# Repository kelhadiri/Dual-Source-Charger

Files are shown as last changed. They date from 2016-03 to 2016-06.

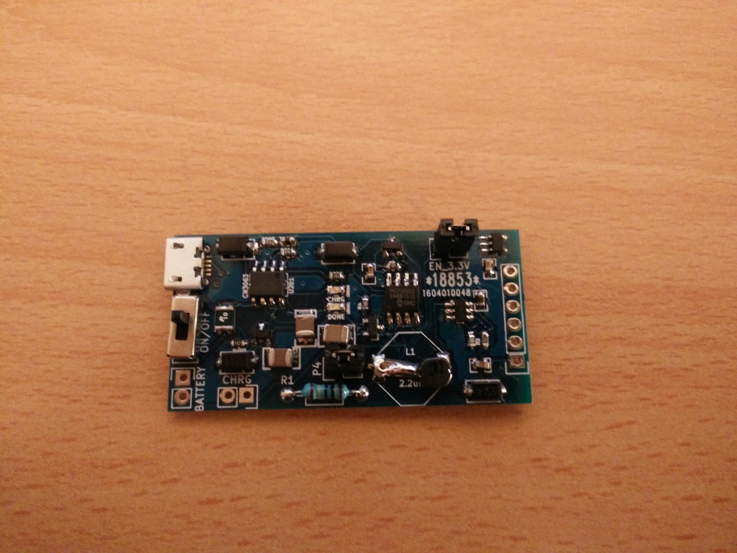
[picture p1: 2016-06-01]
Images/2016-05-27 23.27.27.jpg

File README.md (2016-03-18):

Dual Source Charger
=============
Currently seeking a new, flashier name.

This project is a dual power source charger that breaks out to 3.3v and 5v.

An example use case would be a solar panel or usb connection to charge a lipo driving an ESP8266 or an Arduino.

The dual power circuit is mostly taken from https://github.com/CCHS-Melbourne/ESPlant

CREDITS
------------

This project was designed by [John Spencer](https://github.com/mage0r)
With a special thanks to [Angus Gratton](https://github.com/projectgus)

Made at hackmelbourne.org!

SPECIAL THANKS
------------

To the HackMelbourne (CCHS, http://hackmelbourne.org) community of Melbourne, Australia.

To all other open-source developers whose countless hours supported every other aspect of this design.

DISTRIBUTION
------------
The specific terms of distribution of this project are governed by the
license referenced below. Please contact the copyright owner if you wish to modify the board for distribution. Please utilize this design for personal or research projects. Please acknowledge all contributors.

LICENSE
-------
Licensed under the TAPR Open Hardware License (www.tapr.org/OHL).
The "license" sub-folder also contains a copy of this license in plain text format.

Copyright John Spencer, Angus Gratton 2016

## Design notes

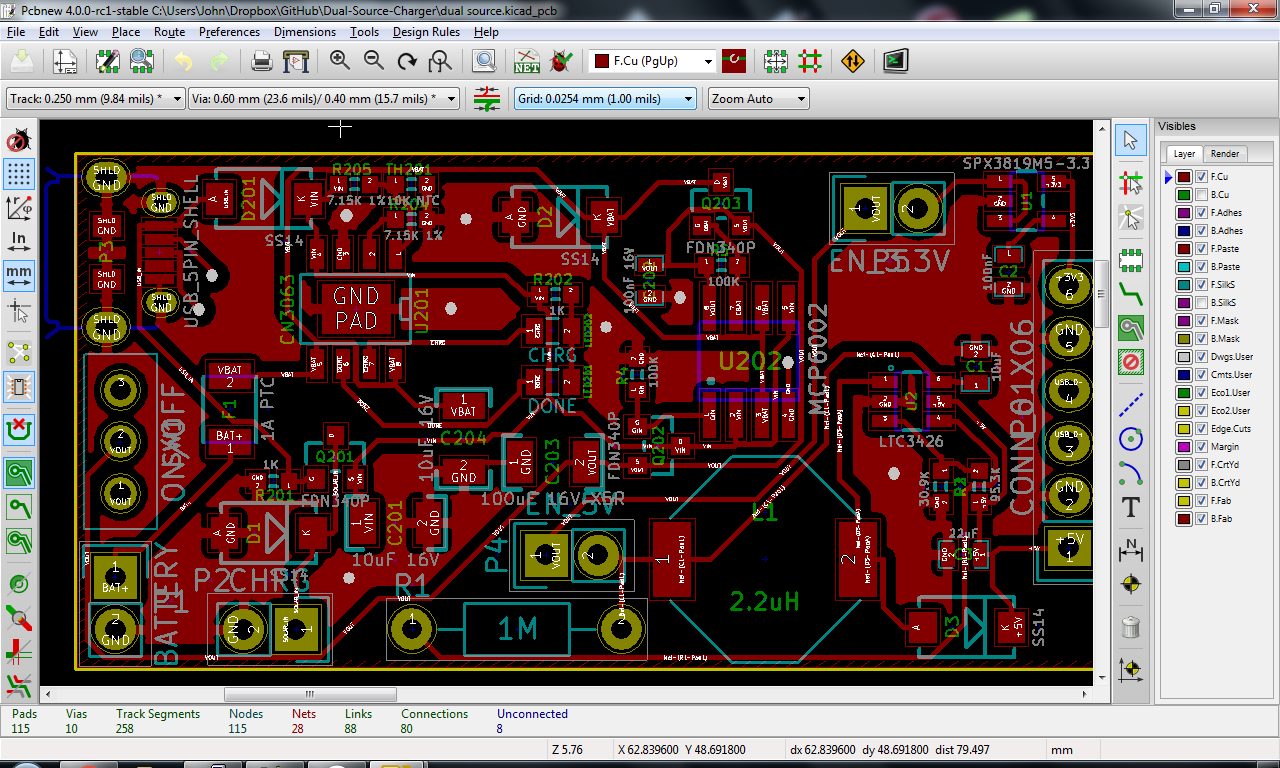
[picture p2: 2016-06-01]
Images/Screenshot 2016-06-01 21.16.20.png

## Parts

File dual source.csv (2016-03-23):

Id | Designator | Package | Quantity | Designation | Supplier and ref
1 | U1 | SOT23-5 | 1 | SPX3819M5-3.3
2 | C1 | 0603_CAP | 1 | 10uF
3 | C2 | 0603_CAP | 1 | 100nF
4 | C3 | 0603_CAP | 1 | 22uF
5 | C201,C204 | 1210_CAP | 2 | 10uF 16V
6 | C202 | 0603_CAP | 1 | 100nF 16V
7 | C203 | 1210_CAP | 1 | 100uF 16V X5R
8 | D1,D2,D3,D201 | DIODE_SMA | 4 | SS14
9 | F1 | 1210 | 1 | 1A PTC
10 | L1 | IND_SRU1038 | 1 | 2.2uH
11 | P1 | Pin_Header_Straight_1x02 | 1 | BATTERY
12 | P2 | Pin_Header_Straight_1x02 | 1 | CHRG
13 | P3 | USB-MICRO-5pin_PTHMOUNT | 1 | USB_5PIN_SHELL
14 | P4 | Pin_Header_Straight_1x02 | 1 | EN_5V
15 | P5 | Pin_Header_Straight_1x02 | 1 | EN_3.3V
16 | P6 | Pin_Header_Straight_1x06 | 1 | CONN_01X06
17 | Q201,Q202,Q203 | SOT23_FET | 3 | FDN340P
18 | R1 | Resistor_Horizontal_RM10mm | 1 | 1M
19 | R2 | 0603 | 1 | 95.3K
20 | R3 | 0603 | 1 | 30.9K
21 | R4,R5 | 0603 | 2 | 100K
22 | R201,R202 | 0603 | 2 | 1K
23 | R204,R205 | 0603 | 2 | 7.15K 1%
24 | SW1 | SS12D00 | 1 | ON/OFF
25 | TH201 | 0603 | 1 | 10K NTC
26 | U201 | CN3063_SOIC8_EP | 1 | CN3063
27 | U202 | SO08_4mm | 1 | MCP6002
28 | LED201 | 0805 | 1 | LED_GREEN
29 | LED202 | 0805 | 1 | LED_RED
30 | U2 | SOT23-6 | 1 | LTC3426

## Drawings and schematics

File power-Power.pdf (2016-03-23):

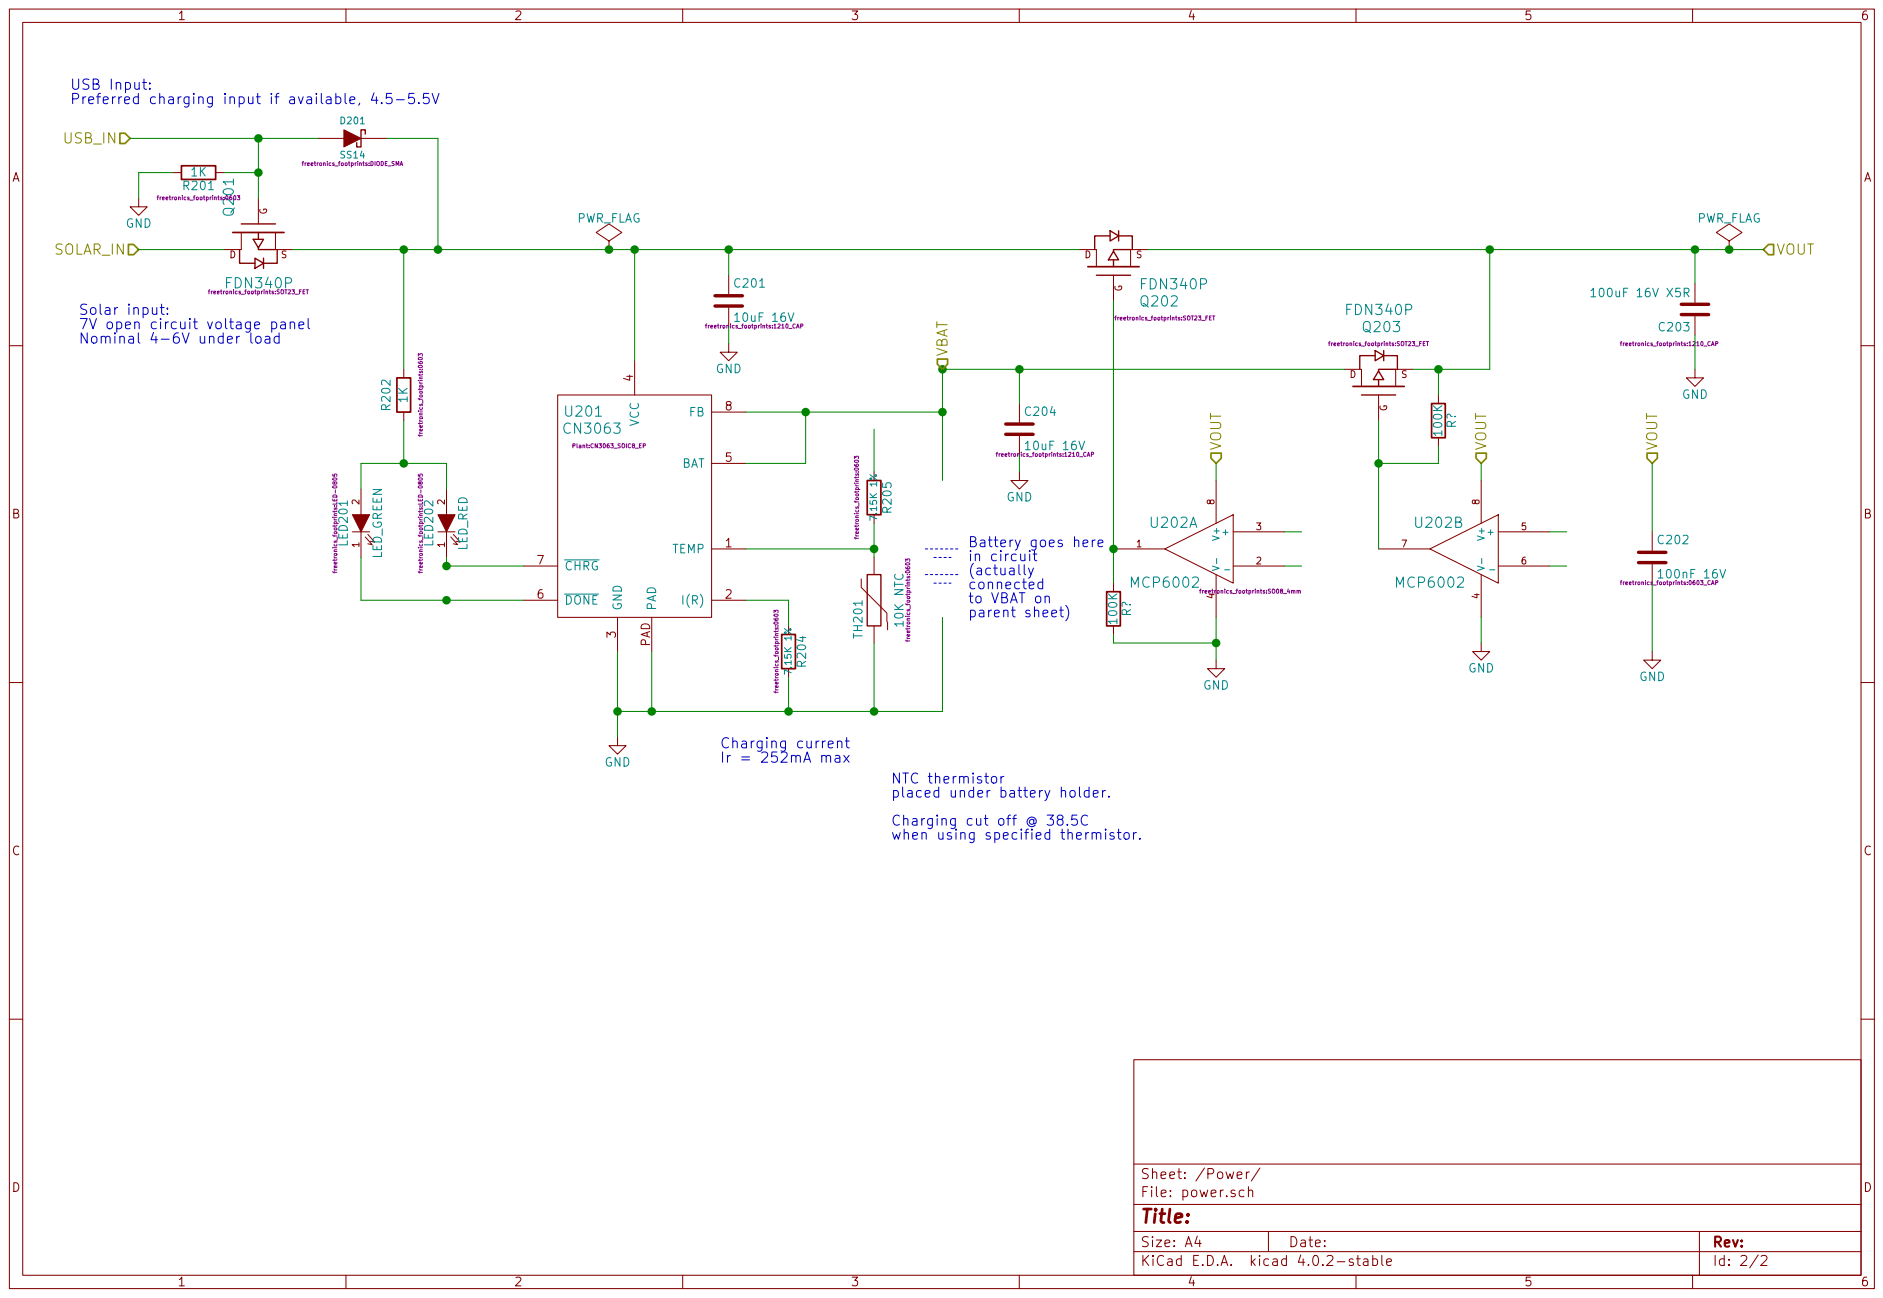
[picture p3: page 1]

freetronics_footprints:SOT23_FET USB Input:
Preferred charging input if available, 4.5-5.5V

when using specified thermistor. C204

4 BAT 5 DONE 6 CHRG 7 FB 8 PAD PAD U201 CN3063

8 U202B MCP6002 VOUT VOUT GND VBAT VBAT VIN

NTC thermistor placed under battery holder.

File: power.sch Sheet: /Power/
Id: 2/2 Title:

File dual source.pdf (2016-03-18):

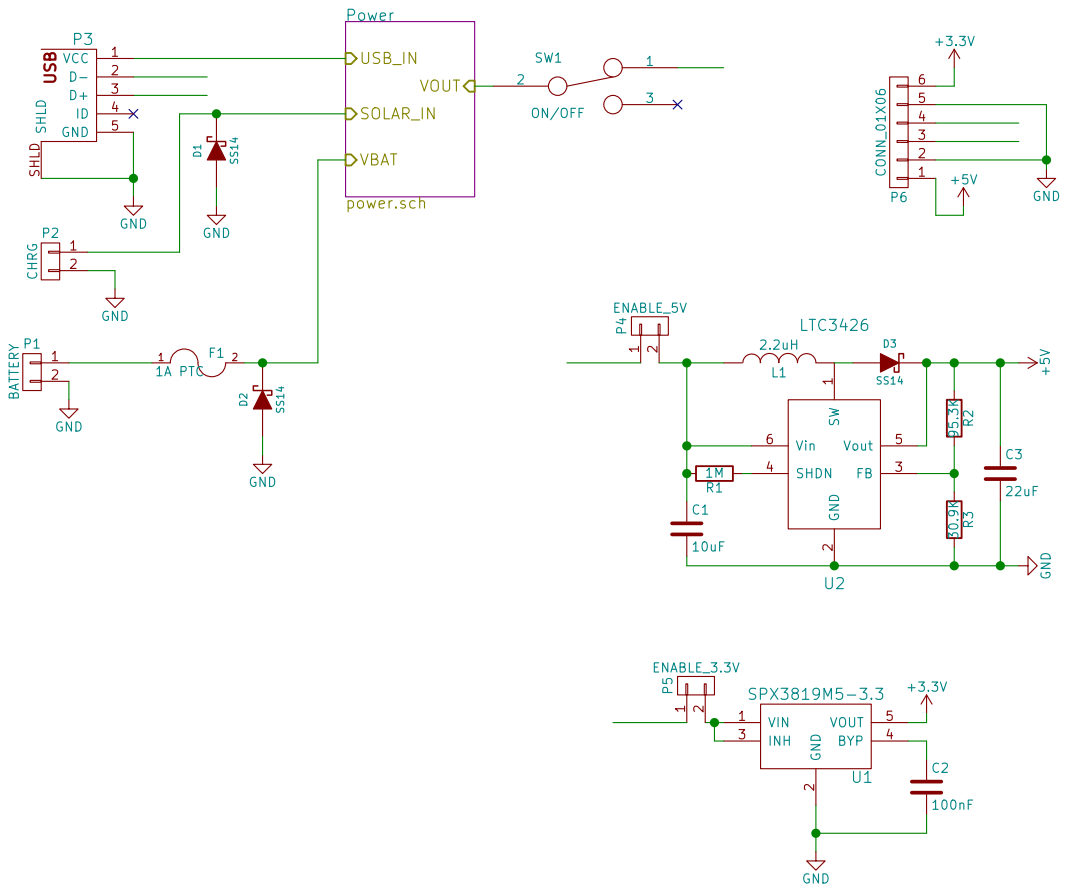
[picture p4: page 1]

2 FB 3 SHDN 4 Vout 5 Vin 6 U2

Id: 1/2 Title: File: dual source.sch Sheet: /

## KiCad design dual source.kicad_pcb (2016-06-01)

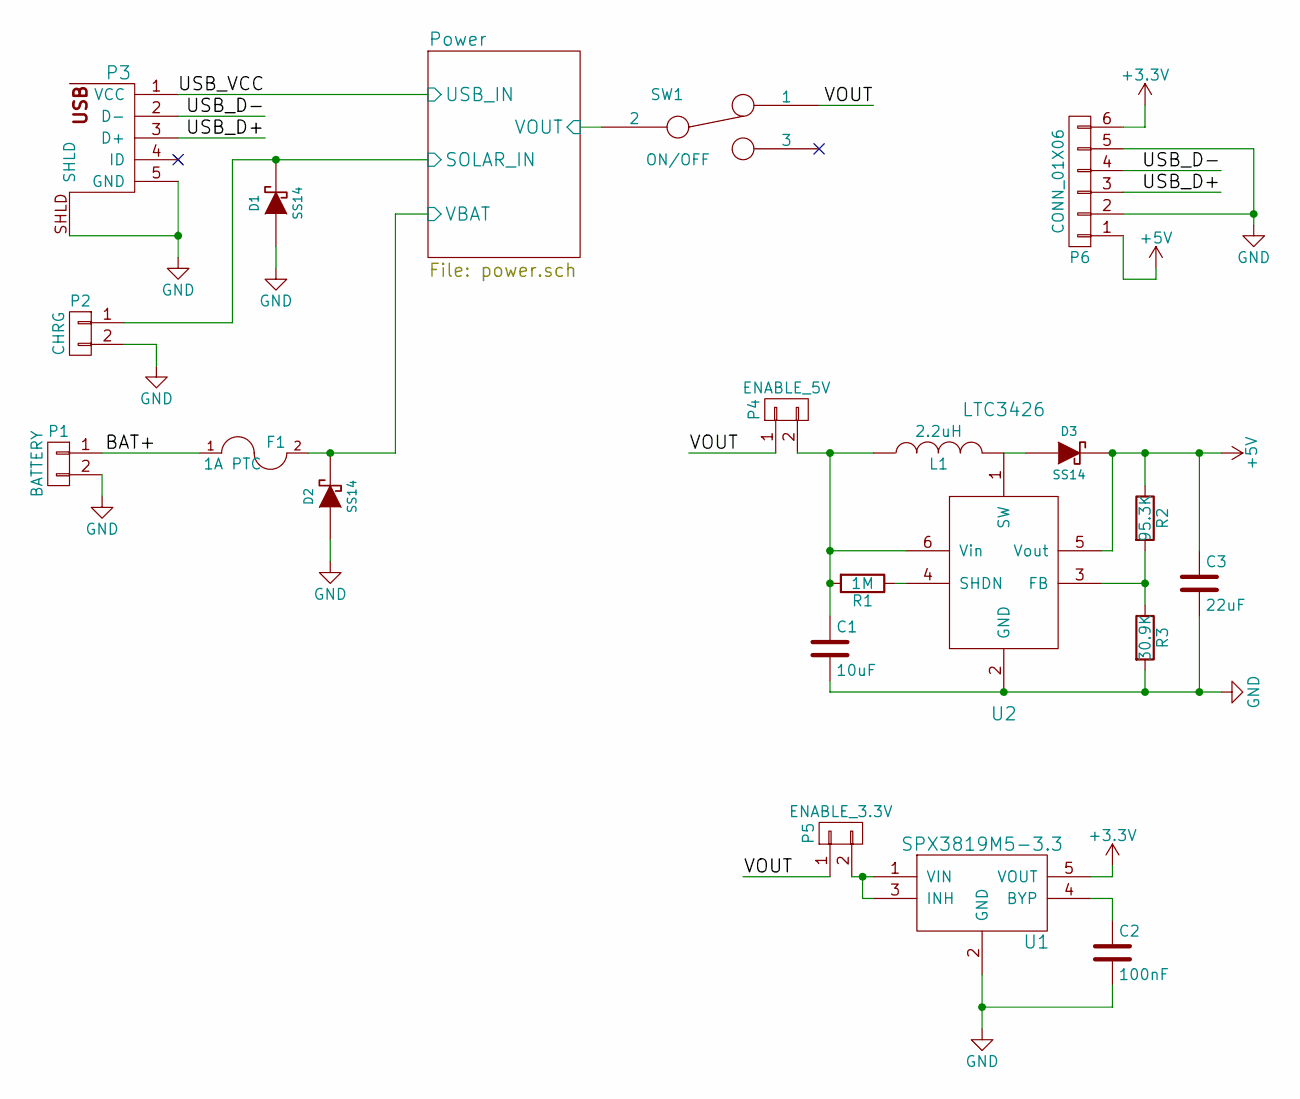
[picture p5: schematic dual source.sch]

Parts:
C1: 10uF; 0603_CAP
C2: 100nF; 0603_CAP
C3: 22uF; 0603_CAP
D1, D2, D3: SS14; DIODE_SMA
F1: 1A PTC; 1210
L1: 2.2uH; IND_SRU1038
P1: BATTERY; Pin_Header_Straight_1x02
P2: CHRG; Pin_Header_Straight_1x02
P3: USB_5PIN_SHELL; USB-MICRO-5pin_PTHMOUNT
P4: ENABLE_5V; Pin_Header_Straight_1x02
P5: ENABLE_3.3V; Pin_Header_Straight_1x02
P6: CONN_01X06; Pin_Header_Straight_1x06
R1: 1M; Resistor_Horizontal_RM10mm
R2: 95.3K; 0603
R3: 30.9K; 0603
SW1: ON/OFF; SS12D00
U1: SPX3819M5-3.3; SOT23-5
U2: LTC3426; SOT23-6

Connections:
+3V3: P6.6, U1.5 (VOUT)
+5V: C3.1, D3.K, P6.1, R2.1, U2.5 (Vout)
/BAT+: F1.1, P1.1
/Power/SOLAR_IN: D1.K, P2.1; also elsewhere on the board
/Power/USB_IN: P3.1 (VCC); also elsewhere on the board
/Power/VBAT: D2.K, F1.2; also elsewhere on the board
/Power/VOUT: SW1.2; also elsewhere on the board
/USB_D+: P3.3 (D+), P6.3
/USB_D-: P3.2 (D-), P6.4
/VOUT: P4.1, P5.1, SW1.1
GND: C1.2, C2.2, C3.2, D1.A, D2.A, P1.2, P2.2, P3.5 (GND), P3.SHLD, P6.2, P6.5, R3.2, U1.2 (GND), U2.2 (GND); also elsewhere on the board
unnamed: C1.1, L1.1, P4.2, R1.2, U2.6 (Vin)
unnamed: C2.1, U1.4 (BYP)
unnamed: D3.A, L1.2, U2.1 (SW)
unnamed: P5.2, U1.1 (VIN), U1.3 (INH)
unnamed: R1.1, U2.4 (SHDN)
unnamed: R2.2, R3.1, U2.3 (FB)

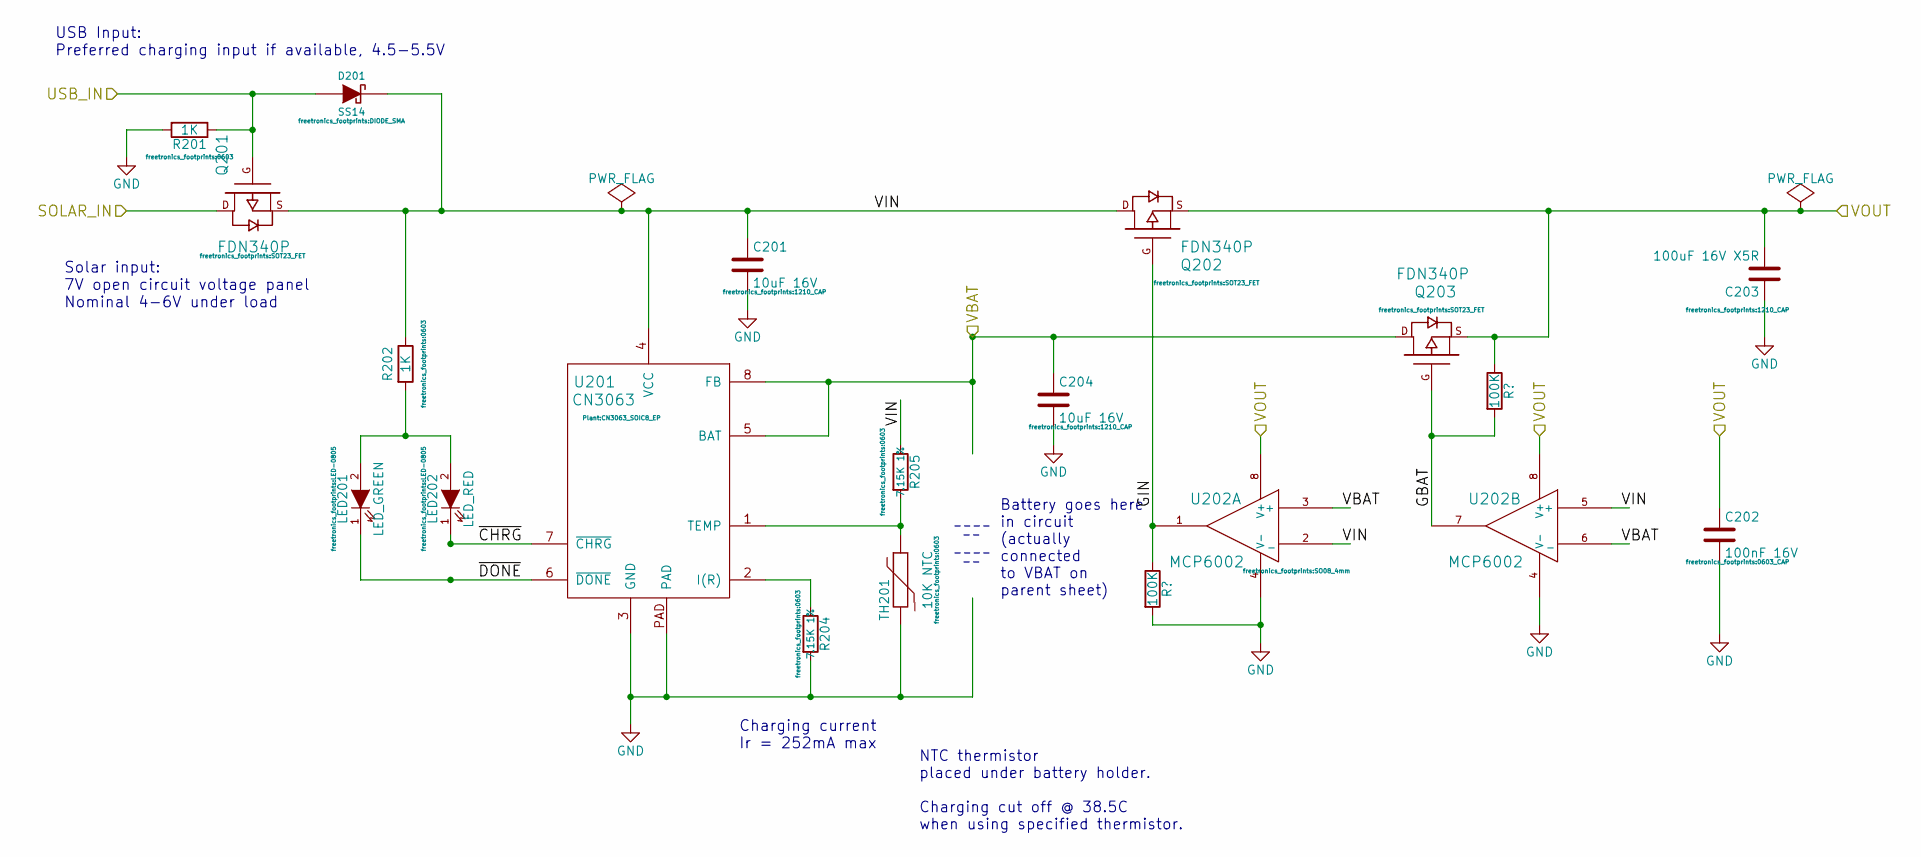
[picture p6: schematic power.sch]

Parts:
C201, C204: 10uF 16V; 1210_CAP
C202: 100nF 16V; 0603_CAP
C203: 100uF 16V X5R; 1210_CAP
D201: SS14; DIODE_SMA
LED201: LED_GREEN; LED-0805
LED202: LED_RED; LED-0805
Q201, Q202, Q203: FDN340P; SOT23_FET
R201, R202: 1K; 0603
R204, R205: 7.15K 1%; 0603
TH201: 10K NTC; 0603; MPN NCP18XH103F03RB
U201: CN3063; CN3063_SOIC8_EP
U202: MCP6002; SO08_4mm

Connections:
/Power/GBAT: Q203.G, U202.7; also elsewhere on the board
/Power/GIN: Q202.G, U202.1; also elsewhere on the board
/Power/SOLAR_IN: Q201.D; also elsewhere on the board
/Power/USB_IN: D201.A, Q201.G, R201.1; also elsewhere on the board
/Power/VBAT: C204.1, Q203.D, U201.5 (BAT), U201.8 (FB), U202.3 (+), U202.6 (_); also elsewhere on the board
/Power/VIN: C201.1, D201.K, Q201.S, Q202.D, R202.1, R205.1, U201.4 (VCC), U202.2 (_), U202.5 (+)
/Power/VOUT: C202.1, C203.2, Q202.S, Q203.S, U202.8 (V+); also elsewhere on the board
/Power/~CHRG: LED202.1 (K), U201.7 (~CHRG)
/Power/~DONE: LED201.1 (K), U201.6 (~DONE)
GND: C201.2, C202.2, C203.1, C204.2, R201.2, R204.2, TH201.2, U201.3 (GND), U201.PAD, U202.4 (V-); also elsewhere on the board
unnamed: LED201.2 (A), LED202.2 (A), R202.2
unnamed: R204.1, U201.2 (I(R))
unnamed: R205.2, TH201.1, U201.1 (TEMP)

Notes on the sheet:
USB Input: Preferred charging input if available, 4.5-5.5V
Solar input: 7V open circuit voltage panel Nominal 4-6V under load
Charging current Ir = 252mA max
Battery goes here in circuit (actually connected to VBAT on parent sheet)
NTC thermistor placed under battery holder. Charging cut off @ 38.5C when using specified thermistor.

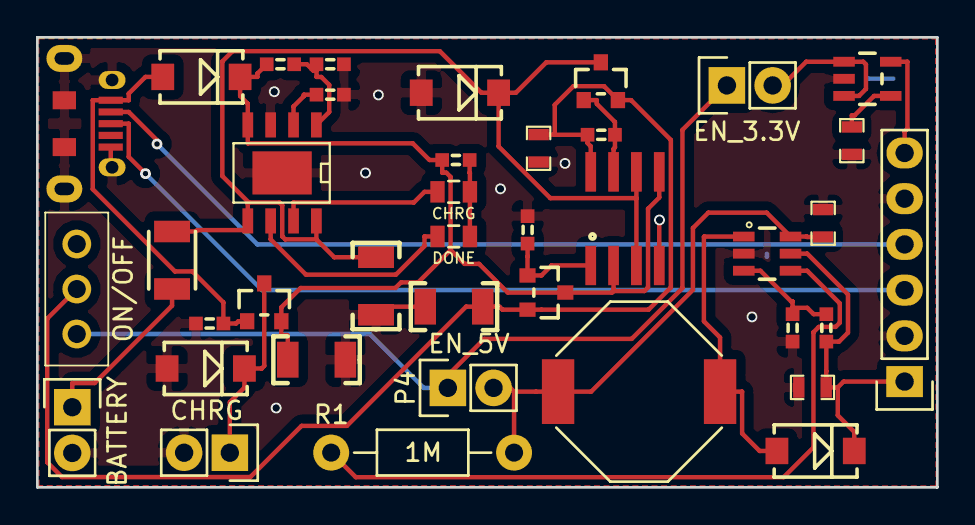
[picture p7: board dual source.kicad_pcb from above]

Board: 2 copper layers, 50.0 x 25.0 mm, 39 parts (0 on the bottom side), 25 nets.

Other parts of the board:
R4, R5: 100K; 0603

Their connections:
/Power/GBAT: R5.2; also elsewhere on the board
/Power/GIN: R4.1; also elsewhere on the board
/Power/VOUT: R5.1; also elsewhere on the board
GND: R4.2; also elsewhere on the board

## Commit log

2016-03-18 Updated Power Circuit.
    [Power.sch, dual source.sch]
2016-03-23 Board design Attempt 1
    [Power.sch, dual source.csv, dual source.dsn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]
2016-03-23 Changed file Power.sch to power.sch for compatability. Redid FTLib submodule because it wouldn't init properly. Git client difference?
    [power.sch]
2016-06-01 Added photo
    [dual source.kicad_pcb]
2016-06-01 Added Board V1 screenshot
